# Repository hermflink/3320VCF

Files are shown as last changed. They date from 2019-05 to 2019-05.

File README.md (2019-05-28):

# 3320VCF
Kicad project files of a CEM3320/AS3320 based VCF. Part of a modular DIY synth project, other modules to follow in other repositories. 

Used the Audio.lib from https://kicad.github.io/symbols/Audio to extend the Kicad library for the AS3320 component.

Designed to work with +/- 15V, but will most likely work fine for +/- 12V as well

The PCB is 9.5 x 5.5 cm and has no PCB-mounting of potmeters, switches, jacks; these are all connected by pin header connectors

Stages 1 and 2 are switchable between HP and LP mode by SW1 and SW2. 
Stages 3 and 4 are fixed on LP mode.
These allow for the following filter modes:
- A: 24dB LP
- B: 12dB BP
- C: 6dB HP + 18dB LP
- D: 6dB LP + 6dB HP + 12dB LP

Background of the mode configurations: https://electricdruid.net/multimode-filters-part-1-reconfigurable-filters/ section Craig Anderton’s Multiple Identity Filter.

Capacitors on pin 4, 5, 11 and 16 should be 1% or less tolerance! 

F1 and F2 fuses are not really required and can be replaced by shorts.

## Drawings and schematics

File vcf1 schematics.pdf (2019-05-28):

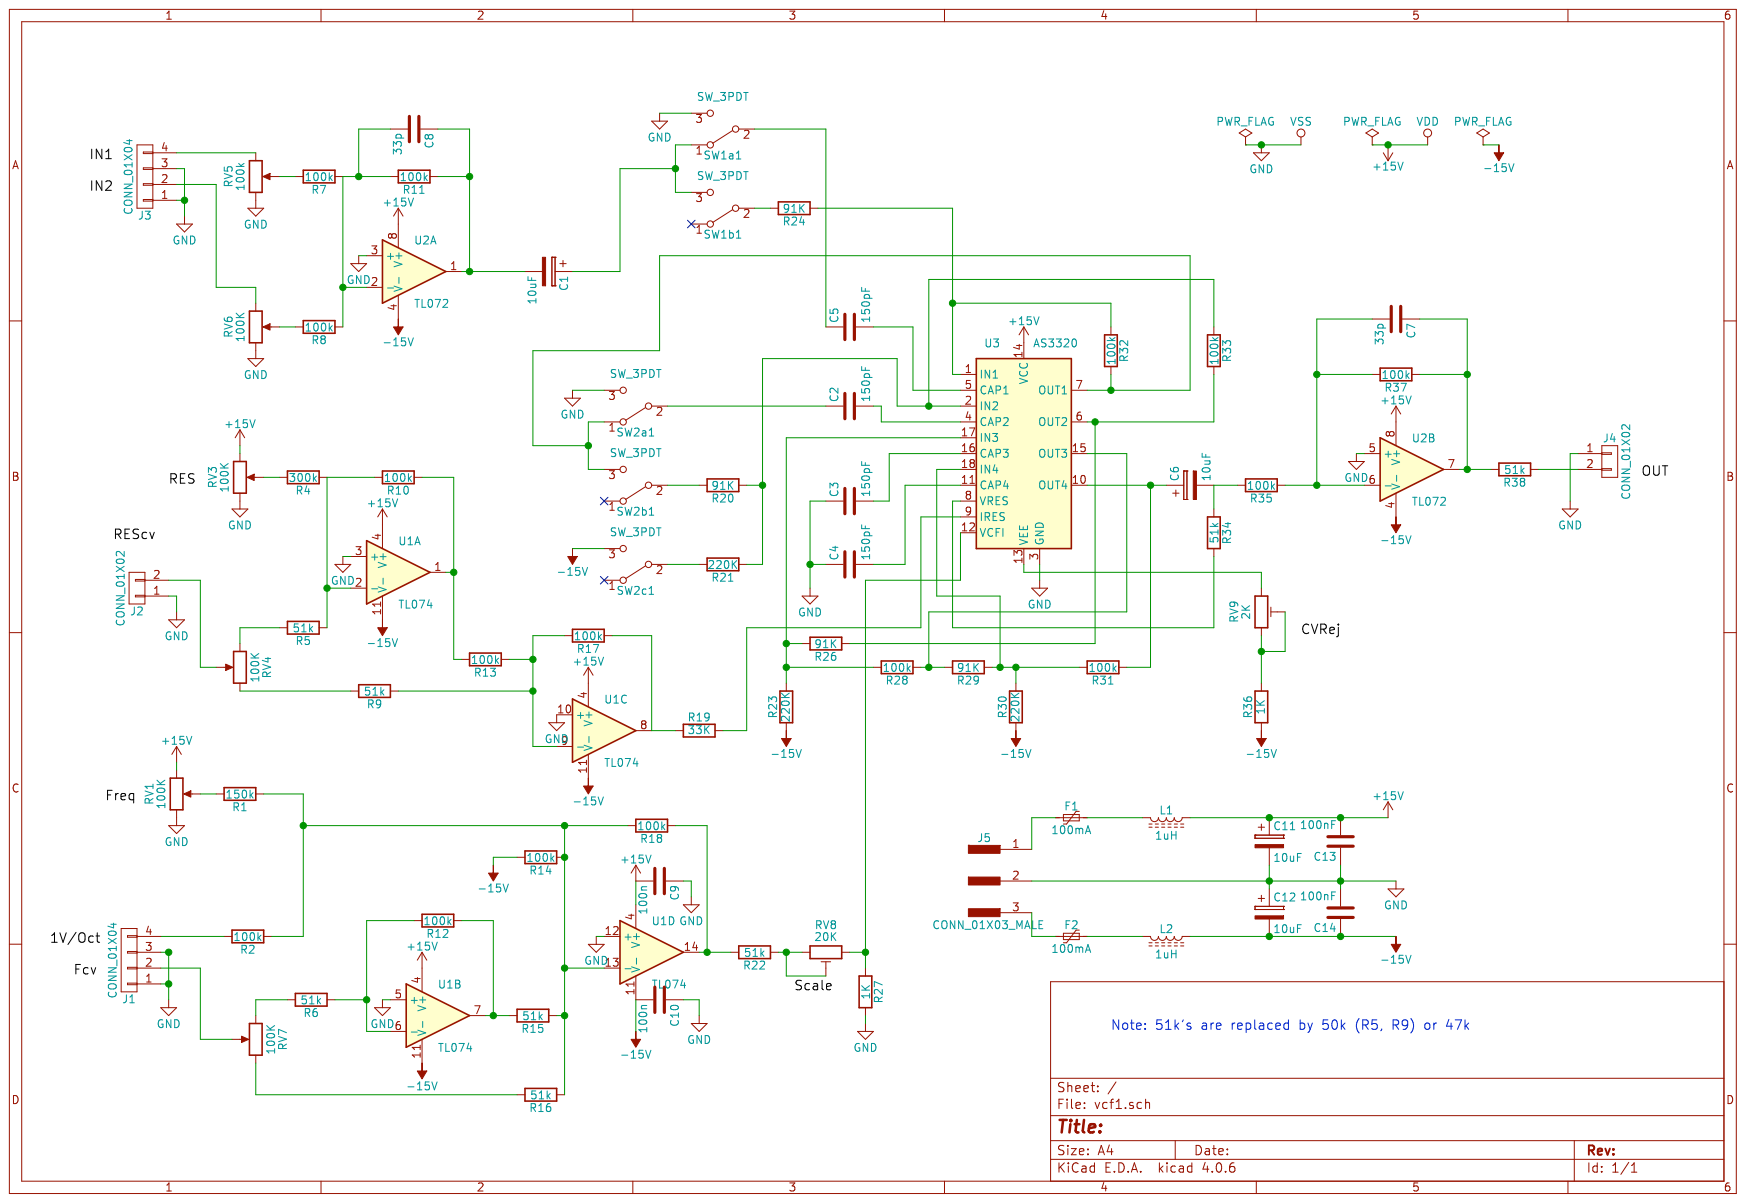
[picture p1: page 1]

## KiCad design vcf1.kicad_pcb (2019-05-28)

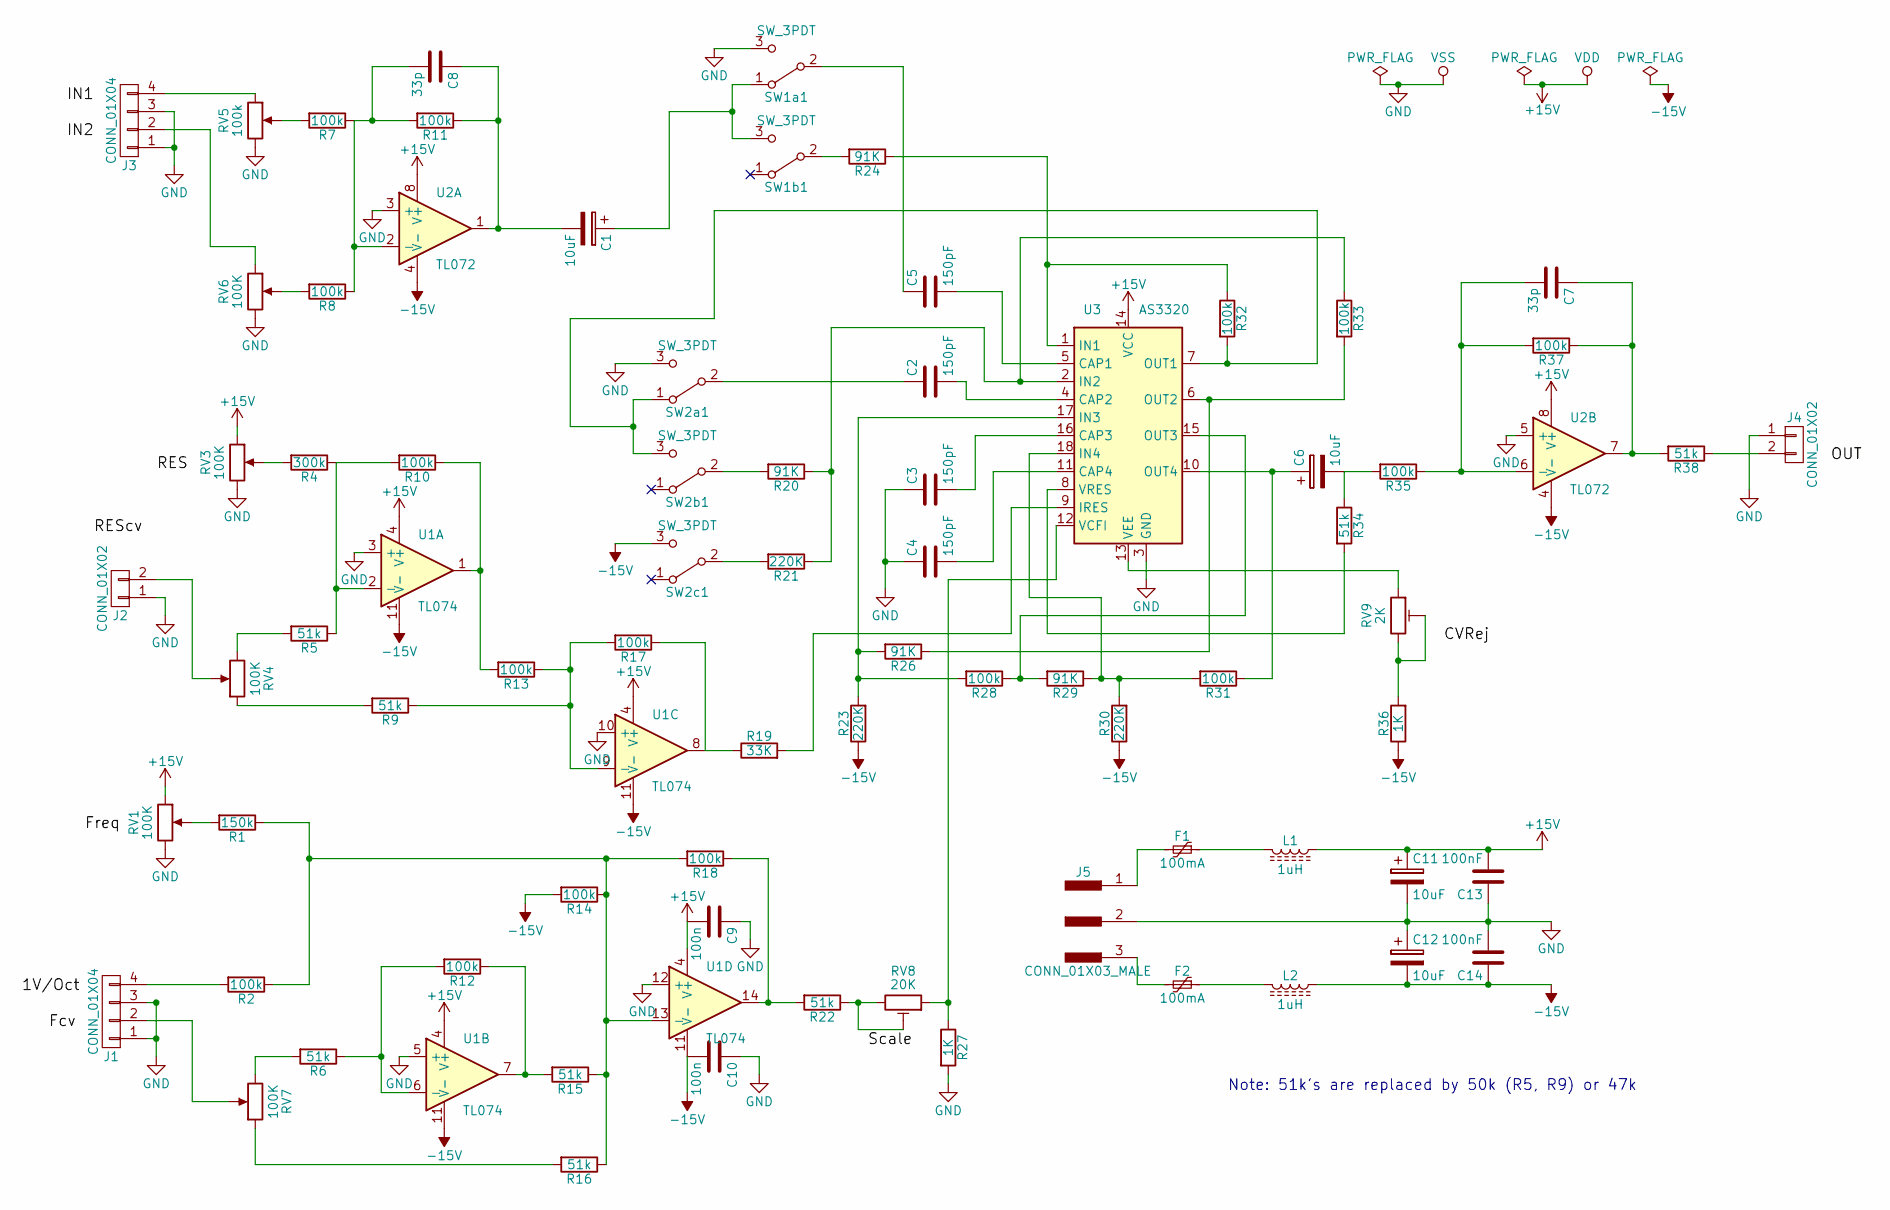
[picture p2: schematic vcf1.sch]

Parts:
C1, C6, C11, C12: 10uF; CP_Radial_D5.0mm_P2.00mm
C2, C3, C4, C5: 150pF; R_Axial_DIN0309_L9.0mm_D3.2mm_P2.54mm_Vertical
C7, C8: 33p; C_Disc_D5.0mm_W2.5mm_P5.00mm
C9, C10: 100n; C_Disc_D5.0mm_W2.5mm_P5.00mm
C13, C14: 100nF; C_Disc_D5.0mm_W2.5mm_P5.00mm
F1, F2: 100mA; C_Disc_D6.0mm_W2.5mm_P5.00mm
J1, J3: CONN_01X04; Pin_Header_Straight_1x04_Pitch2.54mm
J2, J4: CONN_01X02; Pin_Header_Straight_1x02_Pitch2.54mm
J5: CONN_01X03_MALE; Pin_Header_Straight_1x03_Pitch2.54mm
L1, L2: 1uH; L_Axial_L9.5mm_D4.0mm_P2.54mm_Vertical_Fastron_SMCC
R1: 150k; R_Axial_DIN0207_L6.3mm_D2.5mm_P2.54mm_Vertical
R2, R7, R8, R10, R11, R12, R13, R14, R17, R18, R28, R31, R32, R33, R35, R37: 100k; R_Axial_DIN0207_L6.3mm_D2.5mm_P2.54mm_Vertical
R4: 300k; R_Axial_DIN0207_L6.3mm_D2.5mm_P2.54mm_Vertical
R5, R6, R9, R15, R16, R22, R34, R38: 51k; R_Axial_DIN0207_L6.3mm_D2.5mm_P2.54mm_Vertical
R19: 33K; R_Axial_DIN0207_L6.3mm_D2.5mm_P2.54mm_Vertical
R20, R24, R26, R29: 91K; R_Axial_DIN0207_L6.3mm_D2.5mm_P10.16mm_Horizontal
R21, R23, R30: 220K; R_Axial_DIN0207_L6.3mm_D2.5mm_P2.54mm_Vertical
R27, R36: 1K; R_Axial_DIN0207_L6.3mm_D2.5mm_P2.54mm_Vertical
RV1, RV3, RV4, RV6, RV7: 100K; Potentiometer_WirePads_Small
RV5: 100k; Potentiometer_WirePads_Small
RV8: 20K; Potentiometer_Trimmer_Bourns_3296W
RV9: 2K; Potentiometer_Trimmer_Bourns_3296W
SW1a1, SW1b1, SW2a1, SW2b1, SW2c1: SW_3PDT; Pin_Header_Straight_1x03_Pitch2.54mm
U1: TL074; DIP-14_W7.62mm_Socket
U2: TL072; DIP-8_W7.62mm_Socket
U3: AS3320; DIP-18_W7.62mm

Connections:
+15V: C9.2, C11.1, C13.2, L1.1, RV1.1, RV3.1, U1.4 (V+), U2.8 (V+), U3.14 (VCC)
-15V: C10.2, C12.2, C14.1, L2.1, R14.2, R23.1, R30.1, R36.1, SW2c1.3 (C), U1.11 (V-), U2.4 (V-)
GND: C3.1, C4.1, C9.1, C10.1, C11.2, C12.1, C13.1, C14.2, J1.1, J1.3, J2.1, J3.1, J3.3, J4.1, J5.2, R27.2, RV1.3, RV3.3, RV5.3, RV6.3, SW1a1.3 (C), SW2a1.3 (C), U1.3 (+), U1.5 (+), U1.10 (+), U1.12 (+), U2.3 (+), U2.5 (+), U3.3 (GND)
unnamed: C1.1, SW1a1.1 (A), SW1b1.3 (C)
unnamed: C1.2, C8.1, R11.1, U2.1
unnamed: C2.1, SW2a1.2 (B)
unnamed: C2.2, U3.4 (CAP2)
unnamed: C3.2, U3.16 (CAP3)
unnamed: C4.2, U3.11 (CAP4)
unnamed: C5.1, SW1a1.2 (B)
unnamed: C5.2, U3.5 (CAP1)
unnamed: C6.1, R31.1, U3.10 (OUT4)
unnamed: C6.2, R34.1, R35.2
unnamed: C7.1, R37.1, R38.2, U2.7
unnamed: C7.2, R35.1, R37.2, U2.6 (-)
unnamed: C8.2, R7.1, R8.1, R11.2, U2.2 (-)
unnamed: F1.1, L1.2
unnamed: F1.2, J5.1
unnamed: F2.1, L2.2
unnamed: F2.2, J5.3
unnamed: J1.2, RV7.2
unnamed: J1.4, R2.2
unnamed: J2.2, RV4.2
unnamed: J3.2, RV6.1
unnamed: J3.4, RV5.1
unnamed: J4.2, R38.1
unnamed: R1.1, R2.1, R14.1, R15.1, R16.1, R18.2, U1.13 (-)
unnamed: R1.2, RV1.2
unnamed: R4.2, RV3.2
unnamed: R5.2, RV4.3
unnamed: R6.2, RV7.3
unnamed: R7.2, RV5.2
unnamed: R8.2, RV6.2
unnamed: R9.2, RV4.1
unnamed: R10.1, R13.2, U1.1
unnamed: R4.1, R5.1, R10.2, U1.2 (-)
unnamed: R12.1, R15.2, U1.7
unnamed: R6.1, R12.2, U1.6 (-)
unnamed: R9.1, R13.1, R17.2, U1.9 (-)
unnamed: R16.2, RV7.1
unnamed: R17.1, R19.1, U1.8
unnamed: R18.1, R22.2, U1.14
unnamed: R19.2, U3.9 (IRES)
unnamed: R20.1, R21.1, R33.1, U3.2 (IN2)
unnamed: R20.2, SW2b1.2 (B)
unnamed: R21.2, SW2c1.2 (B)
unnamed: R22.1, RV8.2, RV8.3
unnamed: R23.2, R26.2, R28.2, U3.17 (IN3)
unnamed: R24.1, R32.1, U3.1 (IN1)
unnamed: R24.2, SW1b1.2 (B)
unnamed: R26.1, R33.2, U3.6 (OUT2)
unnamed: R27.1, RV8.1, U3.12 (VCFI)
unnamed: R28.1, R29.2, U3.15 (OUT3)
unnamed: R29.1, R30.2, R31.2, U3.18 (IN4)
unnamed: R32.2, SW2a1.1 (A), SW2b1.3 (C), U3.7 (OUT1)
unnamed: R34.2, U3.8 (VRES)
unnamed: R36.2, RV9.2, RV9.3
unnamed: RV9.1, U3.13 (VEE)

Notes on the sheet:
Note: 51k's are replaced by 50k (R5, R9) or 47k

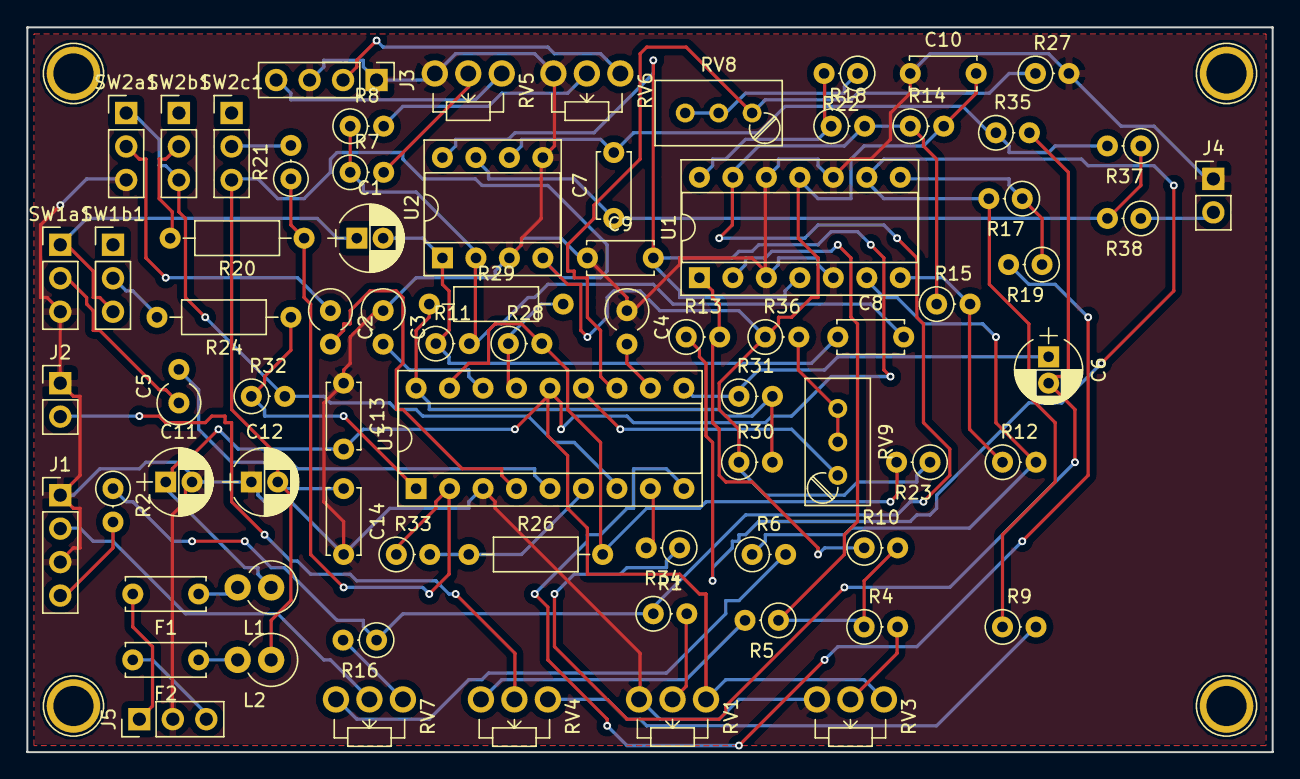
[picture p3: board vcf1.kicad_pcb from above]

Board: 2 copper layers, 94.5 x 55.0 mm, 75 parts (0 on the bottom side), 58 nets.
